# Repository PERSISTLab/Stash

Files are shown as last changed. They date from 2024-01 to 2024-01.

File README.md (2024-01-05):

# Stash: Flexible Energy Storage for Intermittent Sensors

This repository hosts a reference Stash implementation as a peripheral for <a href="https://github.com/PERSISTLab/FlickerPlatform">the Flicker hardware platform</a>

Batteryless sensors promise a sustainable future for sensing, but they face significant challenges when storing and using
environmental energy. Incoming energy can fluctuate unpredictably between periods of scarcity and abundance, and device
performance depends on both incoming energy and how much a device can store. Existing batteryless devices have used fixed
or run-time selectable front-end capacitor banks to meet the energy needs of different tasks. Neither approach adapts well to
rapidly changing energy harvesting conditions, nor does it allow devices to store excess energy during times of abundance
without sacrificing performance.

Stash, a hardware back-end energy storage technique that allows batteryless devices to charge quickly
and store excess energy when it is abundant, extending their operating time and carrying out additional tasks without
compromising the main ones. Stash performs like a small capacitor device when small capacitors excel and like a large
capacitor device when large capacitors excel, with no additional software complexity and negligible power overhead. We
evaluate Stash using two applications—temperature sensing and wearable activity monitoring—under both synthetic solar
energy and recorded solar and thermal traces from various human activities. Our results show that Stash increased sensor
coverage by up to 15% under variable energy-harvesting conditions when compared to competitor configurations that used
fixed small, large, and reconfigurable front-end energy storage.

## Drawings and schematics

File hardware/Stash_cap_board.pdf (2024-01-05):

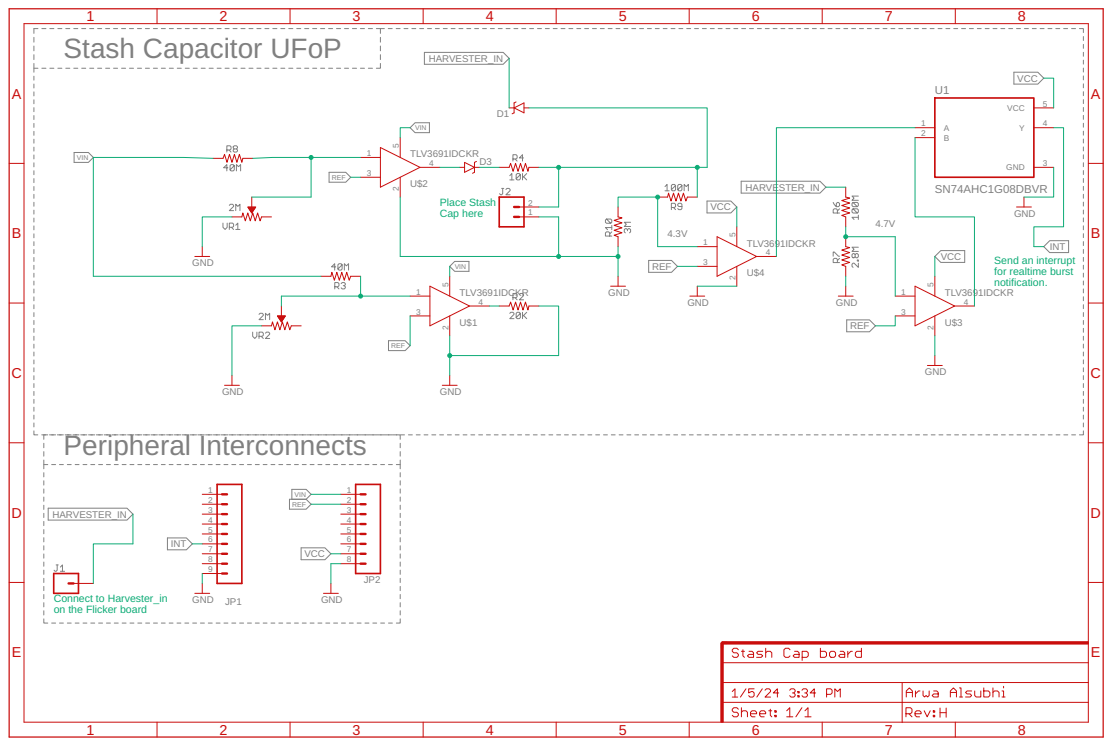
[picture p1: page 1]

Stash Capacitor UFoP

Connect to Harvester_in
on the Flicker board

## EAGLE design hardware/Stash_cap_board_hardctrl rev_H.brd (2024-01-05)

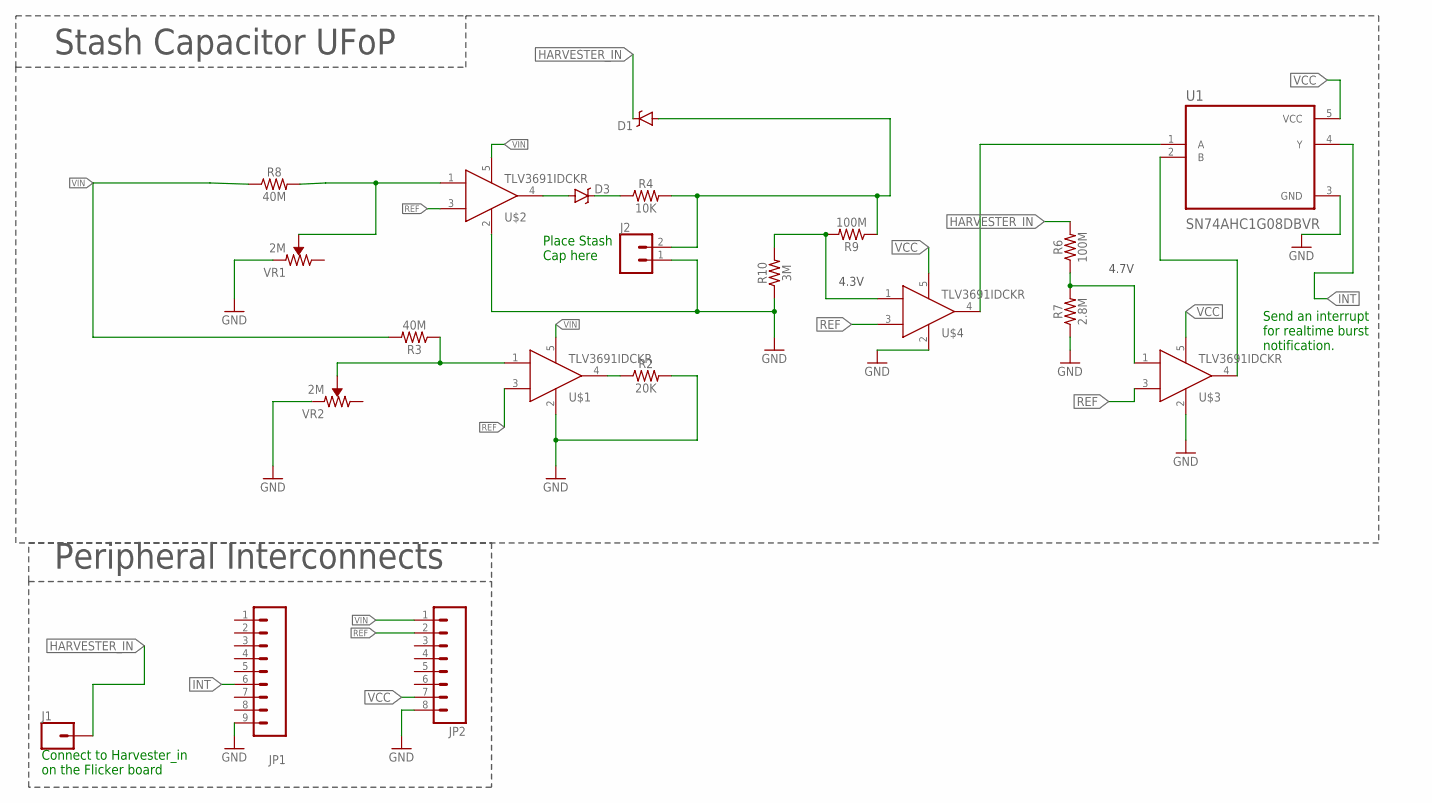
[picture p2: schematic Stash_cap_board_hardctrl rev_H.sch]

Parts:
D1, D3: RB751; SOD-523; MPN BAS40-02V-V-G-08; DIGIKEY BAS40-02V-V-G-08GICT-ND
J1: CONN_01; 1X01
J2: CONN_02; 1X02
JP1: M091.27MM; 1X09-1.27MM; MANUFACTURERPARTNUMBER GRPB091VWVN-RC; DIGIKEY S9014E-09-ND
JP2: M081.27MM; 1X08-1.27MM; MANUFACTURERPARTNUMBER GRPB081VWVN-RC; DIGIKEY S9014E-08-ND
R2: 20K; 0805
R3, R8: 40M; 0805
R4: 10K; 0603
R6, R9: 100M; 0805
R7: 2.8M; 0805
R10: 3M; 0805
U1: SN74AHC1G08DBVR; SOT95P280X145-5N
U$1, U$2, U$3, U$4: TLV3691IDCKR; SOT353
VR1, VR2: 2M; TRIMPOT-SMD-3MM-CLOSED

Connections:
CAP_VCC: D1.A, J2.2, R4.2, R9.1
GND: J2.1, JP1.9, JP2.8, R2.2, R7.1, R10.1, U1.3 (GND), U$1.2, U$2.2, U$3.2, U$4.2, VR1.1 (CCW), VR2.1 (CCW)
HARVESTER_IN: D1.C, J1.1, R6.2
INT: JP1.6, U1.4 (Y)
unnamed: D3.A, U$2.4
unnamed: R2.1, U$1.4
unnamed: R8.2, U$2.1, VR1.2 (WIPER)
unnamed: R3.1, U$1.1, VR2.2 (WIPER)
unnamed: R6.1, R7.2, U$3.1
unnamed: D3.C, R4.1
unnamed: R9.2, R10.2, U$4.1
unnamed: U1.2 (B), U$3.4
unnamed: U1.1 (A), U$4.4
REF: JP2.2, U$1.3, U$2.3, U$3.3, U$4.3
VCC: JP2.7, U1.5 (VCC), U$3.5, U$4.5
VIN: JP2.1, R3.2, R8.1, U$1.5, U$2.5

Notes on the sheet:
Peripheral Interconnects
Stash Capacitor UFoP
4.7V
4.3V
Send an interrupt for realtime burst notification.
Connect to Harvester_in on the Flicker board
Place Stash Cap here

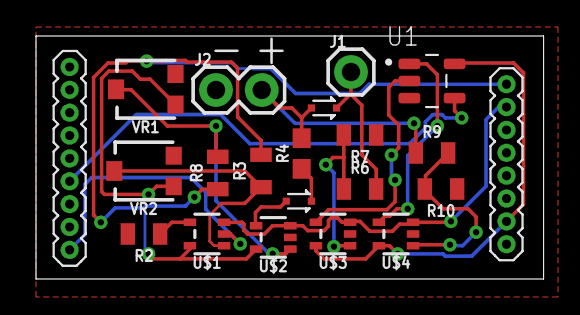
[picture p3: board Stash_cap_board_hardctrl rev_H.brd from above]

Board: 2 copper layers, 28.2 x 13.5 mm, 21 parts (0 on the bottom side), 16 nets.

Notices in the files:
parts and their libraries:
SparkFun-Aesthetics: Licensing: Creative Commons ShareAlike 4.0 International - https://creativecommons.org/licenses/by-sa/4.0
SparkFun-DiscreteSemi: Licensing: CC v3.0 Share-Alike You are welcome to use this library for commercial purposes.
